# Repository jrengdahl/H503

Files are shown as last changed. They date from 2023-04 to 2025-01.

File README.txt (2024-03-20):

STM32H503RB test board and firmware

This project includes a small OSHPark board for the new H503
microcontroller from ST MIcro, and firmware to run on the board. The
firmware includes OpenMP support for this bare metal microcontroller.

THE CHIP

The STM32H503 is a low-end microcontroller by ST Microelectronics:
-- Cortex-M33 CPU
-- 250 MHz
-- 128K flash
-- 32K RAM
-- typical peripherals for a small micro, including USB Device.
-- ETM trace port

When this chip first became available in early March of 2023, it was in
stock at Mouser for $4.33, and I was able to obtain a few. As of March
2024 they are available in small quantities from Digikey, directly from
ST Micro, and some other suppliers. Try findchips.com to search for
availability. Often such chips are more easily available on a Nucleo
board (although the Nucleo boards do not have trace connectors).

The spec clock for the H503 is 250 Hz. It seems to run reliably up to
350 MHz, and sometimes 400 MHz, at room temperature, and not using all
the chip's features. YMMV.

THE FIRMWARE

The firmware build is managed by an STM32CubeIDE project. The skeleton
of the project was auto-generated from the H503.ioc file. My firmware is
a simple command line interpeter with the following commands:

-- dump memory
-- modify memory
-- fill memory
-- RAM test
-- input from a pin
-- output to a pin
-- calibrate the CPU clock (to make sure the crystal, PLL, and spin-delay loop are correct)
-- set the CPU clock to a given frequency
-- execute a single LDR to a given memory location
-- execute a single STR to a given memory location
-- print a summary of the flash and RAM
-- run a benchmark of the thread switcher
-- display the on-chip temperature sensor reading
-- dump the thread stacks
-- display the state of the free memory system
-- run various OpenMP tests
-- set the debug verbosity level
-- print the help

The command line processor is simple and easily expanded with new commands.

The firmware takes about 40K of flash and 24K of RAM.

For similar L412 and H743 projects, rather than using an FTDI
USB-to-serial cable, or an on-board USB-to-serial chip, I decided to
learn how to use the native on-chip USB for the serial console. I got a
lot of help from Jean Roch's tutorial on using the STM32 USB CDC
library:
https://nefastor.com/microcontrollers/stm32/usb/stm32cube-usb-device-library

When I went to port this firmware over to the H503 I found that, since
the chip is very new, the USB_Device library is not yet available. With
some help from ST tech support, I was able to borrow code from similar
chips (the H743 and L552), and adapt it to the H503.

THREADS

I usually write bare metal firmware, with no OS or RTOS, but I use a
simple non-preemptive threading system, which enables me to architect a
system as a set of cooperating processes. As the concept developed over
many years it has gone by the name of "wait-wake", "plastic fork", and
"not-an-OS", but currently goes by the name of "Bear Metal Threads". Its
characteristics include:

-- very small: the code that gets used at runtime consists of 23 ASM
   instructions. There is a little more for creating threads at powerup. 
-- very fast: a thread switch takes 125 nanoseconds on a 250 MHz M33.
-- non-preemptive: there is no scheduler.
-- threads can run at interrupt level, which can provide prioritization.

OPENMP

One reason I created this project is as a platform to experiment with
bare metal OpenMP. 

OpenMP is a parallel processing extension for C/C++ and Fortran that is
built into GCC. It can be used on modern multi-core PCs running Windows
and Linux. It is most commonly associated with massively parallel
supercomputers such as Frontier and Fugaku (https://www.top500.org). I
aim to show that it can also be useful for multi-threaded and parallel
programming on single and multi-core embedded processors.

The following OpenMP features are working:
-- parallel
-- parallel for
-- single
-- task
-- firstprivate

I have started migrating the powerup code and command line interpreter
to using OpenMP primitives rather than the older threading calls to
spawn new threads.

This is experimental and ongoing.

THE GCC TOOLCHAIN

There are two reasons this firmware requires a special toolchain:

-- The threading system reserves r9 for the preempted thread stack. The
entire firmware must be compiled with the GCC flag "-ffixed-r9", so that
user code does not clobber r9. According to the AAPCS specification, r9
should be untouched by libraries. I have never seen a precompiled ibrary
that observes this rule. Fortunately, the ST-supplied code is always
compiled along with your firmware. Unfortunately, the precompiled newlib
that comes with the standard ARM bare metal GCC toolchain does not
follow the rule and clobbers r9.

-- GCC includes OpenMP, however it is only enabled for platforms that
have a large OS, such as Linux or Windows. The bare metal versions of
the toolchain do not have OpenMP enabled. My build of the GCC bare metal
toolchain has OpenMP enabled.

The Cortex-M33 GCC 12.2 toolchain to be used with this project is found at:
https://github.com/jrengdahl/cross/releases

THE BOARD

The KiCAD project for the board is included, or you can order three
boards from OSHPark for $16.
https://oshpark.com/shared_projects/t9n5Q26a

The board uses the Arduino Nano form factor, but is only partially
pin-compatible. It will fit into a Nano socket, such as this:
https://www.amazon.com/gp/product/B095XVVGQ8. Since the H503 is only
available in a 64-pin LQFP at the moment, in order to fit it on the
board I had to turn it 45 degrees, and delete the middle three pins from
each row of the connector. On the other hand, all pins on the
microcontroller either have a job, are brought out to pins, or are
brought out to solderable test points.

Interesting things about the board are:
-- Arduino Nano form factor
-- can be powered from the USB port
-- uses the on-chip USB for a virtual serial console
-- trace port
-- SPI flash

Otherwise the board is very minimal: power regulator, crystal
oscillator, connectors, a reset button, the BOOT0 button is also an GPIO
input, and one LED. I put a Winbond SPI flash on it because I want to
learn how to use them.

The microcontroller pinout is captured in a CubeMX project,
H503.kicad/H503.ioc. This is a sample CubeMX project I used as reference
for the board design, which shows a possible maximum usage of the pins.
The separate ./H503.ioc used by the firmware project only enables the
pins that are currently supported by the firmware.

Building the board is not hard. I do my soldering under a 1959
StereoZoom microscope using a very fine-tip pencil, and SMT solder paste
applied with a toothpick, or wire solder for through-hole parts. One
thing to watch out for is the USB connector. If you use too little
solder you risk ripping the connector off the board if you are not real
careful with the USB cable. If you use too much solder it can puddle
under the connector and short out the signal pins.

There is a newer version of the board that was manufactured by JLCPCB.
All the small commodity parts are located on the bottom side and are
soldered by JLCPCB. The CPU, connectors, and a couple parts that are
not sourced by JLCPCB are on the top side and have to be hand soldered.

The directory H503-0.1.oshpark contains the KiCad files that were used
for the OSHPark board. The directory H503-0.2.jlcpcb contains the KiCad
files for the JLCPCB board. The "production" subdirectory contains the
zip file that was uploaded to JLCPCB, including the BOM and
pick-and-place files. The directory H503-0.3 contains a slight
modification to the H503-0.2 board layout; mainly, the oscillator
footprint uses larger pads to make it easier to solder by hand. (I have
not had the 0.3 board built yet).

TRACE

One of my retirement presents to myself was a Segger J-Trace probe, so
I put a 20-pin trace port on this board rather than the usual four-pin
Serial Wire Debug port. If you don't have a trace probe you can populate
a 10-pin connector instead, and use a J-link or ST-Link probe. (You
can't fit a 10-pin connector onto a 20 pin header because the end of the
connector won't fit between the 5th and 6th pairs of pins).

One reason I prefer the M7 processors is that they include an on-chip
trace buffer, and a trace probe is not required. I use the free Segger
Ozone debugger, which can display trace for either on-chip or off-chip
trace. Unfortunately, since COVID, M7 chips are nearly impossible for a
hobbyist to obtain. That is why I have been focusing on the L412, and
more recently the H503. (Try lcsc.com if you need M7 chips, I found some
affordable H7B0).

In order to use ETM trace with Cortex-M4 and Cortex-M33 chips, the
following is required:

-- a chip that has trace port or on-chip trace buffer. As far as I know,
all STM32 in 100 pin packages or larger have trace ports. Trace ports on
smaller pinouts are less common. There is no easy way to find which chips
have trace capability, other than reading many data sheets. So far I
have found the STM32H503 and STM32L412 in LQFP-64, and the L412 in
LQFP-32, have 5-pin trace ports. In fact, the L412 seems to be the only
STM32 in LQFP-32 that has a trace port.

Some Cortex-M7 chips from ST Micro have 2K or 4K on-chip trace buffers.
These can be used with Ozone and an inexpensive J-Link Edu, though the
trace depth is limited.

-- a trace probe (unless you have an on-chip trace buffer). Trace probes
are expensive. I am familiar with Lauterbach, which costs in the
vicinity of $10,000. My Segger J-Trace was around $1800. In the UK or EU
check out pdqlogic.com, but they won't ship to the USA. Some people have
used inexpensive USB logic analyzers with the Sigrok software to capture
trace, but such a solution is harder to use
(https://essentialscrap.com/tips/arm_trace).

-- a trace capable debugger. I use Segger Ozone, which is included 
with J-Trace, or it is free for non-commercial use.

-- you have to allocate from two to five pins for the trace port. I have
always used the full five pins.

-- Your board has to have a trace port connector. The traces from the
chip to the connector should be laid out with high speed signalling in
mind. In theory, it might be possible to wire a trace probe to I/O pins
of a Nucleo board, but I would not expect this to work well at fast
clock rates. Though the H503 can run up to 250 MHz (400 MHz overclocked),
on my board the trace becomes flakey above 100 MHz.

-- You need to configure the trace pins. There are two ways to do this:

     -- your software can setup the pins and the ETM at powerup.
        Currently my L412 software does it this way. I based my ETM
        setup code on this project:
        https://github.com/PetteriAimonen/STM32_Trace_Example

     -- You can obtain or write an Ozone script to setup the trace
        pins. Once the pins are setup, Ozone can deal with the ETM and
        TPIU on its own. Segger provides compiled (.pex) scripts for
        certain chips. If your chip is not supported, or you have used a
        different pinout than Segger used, you either have to get them
        to create a .pex for you, or you can write your own script. This
        project includes a redistributable .jdebug script which sets up
        the pins for the H503.

   Having tried both methods, using the script works a lot better. Note
   that the H503 uses a different ETM than the L412. The L412 code will
   not work for the H503. It would be fairly difficult to research and
   write the ETM-M33 setup code, since you not only have to deal with
   the pins, but also the ETM and TPIU, for which I could find no
   easy-to-use documentation or example code. Also, when using the
   script, the trace starts at powerup, whereas if your software sets up
   the ETM, the trace only works after your code runs, and you have to
   stop and restart your program after the setup code before Ozone
   starts receiving trace data.

RTOS-AWARE TRACE

Segger's Ozone debugger can detect RTOS thread switches in order to make
the trace easier to read and understand. If you are using a supported
RTOS they have RTOS-awareness modules you can download and use. If your
RTOS is not supported, or home-brewed like mine, you can tell Ozone
about the thread switching code in the Ozone startup script. The .jdebug
script included with this project does that. There are two prequisites:
your thread switch code must exist in a subroutine call that Ozone can
find, and you have to use Dwarf-4 debug info. Newer editions of GCC,
such as 12.2, emit Dwarf-5 debug data by default, so you have to pass
-gdwarf-4 to the GCC and G++ compilers.

The newer version of Ozone supports Dwarf-5, but I have not tried
Dwarf-5 yet.

JLINK

There is an alternate H503-edu.jdebug file that works with a non-trace
Jlink. The J-link Edu comes with a 10-pin high density conector that
will work with this board if you install a 10 pin connector (or cut half
the pins from the 20-pin connector). Jlink EDU is $60 at
https://shop-us.segger.com/product/j-link-edu-mini-8-08-91 or
at Mouser or Digikey.

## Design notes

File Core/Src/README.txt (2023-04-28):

Bear Metal Shell
A small embedded command line processor.

Bear Metal Threads
Extremely minimal non-preemptive thread switching for bare metal.

The original version of this code was developed in 2009 for a home
project that was intended to result in a digital controller for my
trolling motor that had a burned out speed control switch. The
controller was a Luminary Micro Cortex-M3 eval board. The motor driver
was made for RC model planes. It worked fine on dry land, but when I got
it into the water it went poof after about a minute and the magic smoke
came out. Evidently the motor's resistance and current were compatible
with the RC drive circuit, but the inductance of the trolling motor was
a lot more than an airplane motor. Under load, the inductive kick took
out the catch diodes.

The motor controller wound up in the scrap pile, I got a new mechnical
switch for the boat motor and gave it away, but the firmware lives on,
and on, and on. It found many uses, including some products of my
employer. The files here are derived from the original code I wrote for
the Luminary Micro Cortex-M3, or are newly written since I retired.

Manifest

My contributions in this directory include, but are not necessarily
limited to the following files. The list includes the #include files
which should be located in a nearby direcetory such as ../Inc. Most
other files in these directories are from ST Micro, and are probably 
auto-generated by STM CubeMX.

README.txt          This file
RamTest.cpp         A minimal RAM tester
background.cpp      Powerup init for my code, then it becomes the background polling loop
bear.cpp            Print the Bear Metal logo.
bogodelay.cpp       Delay the specificed number of CPU cycles
dump.cpp            Memory dump
getline.cpp         Get a line of input, with command line editing and history
interp.cpp          The command line interprter
libgomp.cpp         OpenMP library for bare metal (experimental, under development)
printf.cpp          printf
serial.cpp          Console interface routines for serial, USB VCP, or whatever 
summary.cpp         Print a summary of the memory
thread.cpp          The implementation of Bear Metal Threads

CriticalRegion.hpp  Disable interrupts around a block of code. Safe for break, return, etc.
FIFO.hpp            A wait-free, single-writer-single-reader FIFO (aka ring buffer)
ThreadFIFO.hpp      A subclass if FIFO which implements thread suspend/resume.
atomic.h            Wrap a small block of code with LDREX/STREX, making its operation on a variable atomic.
bogodelay.hpp       For bogodelay.cpp
boundaries.h        Mapping of linker regions for summary.cpp
cmsis.h             A wrapper for cmsis_compiler.h which remedies some ommissions.
cyccnt.hpp          Support for the cycle counter, including high precision timing measurements.
libgomp.hpp         For libcomp.cpp
local.h             Local config and definitions for interp, getline, printf, etc.
random.hpp          A famous random number generator, simple, fast, and fairly good.
serial.h            For serial.cpp.
thread.hpp          For Thread.cpp.

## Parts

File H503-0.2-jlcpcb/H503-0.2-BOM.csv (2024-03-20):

Id | Designator | Footprint | Quantity | Designation | Supplier and ref
1 | X1 | Oscillator_SMD_ECS_2520MV-xxx-xx-4Pin_2.5x2.0mm | 1 | ECS-2520MV-080-CN
2 | TP1,TP3,TP7,TP14,TP9,TP6,TP11,TP5,TP8,TP12,TP4,TP13,TP2,TP10 | TestPoint_THTPad_D1.0mm_Drill0.5mm_min | 14 | TestPoint
3 | BOOT1,RESET1 | SW_SPST_B3U-1000P | 2 | SW_Push
4 | J3 | PinHeader_2x10_P1.27mm_Vertical | 1 | Conn_02x10_Odd_Even
5 | U4 | SOT-23-6 | 1 | WE-TVS-82400102
6 | J4 | USB_Micro-B_Amphenol_10118194_Horizontal | 1 | USB_B_Micro
7 | U2 | LQFP-64_10x10mm_P0.5mm | 1 | STM32H503RBTx
8 | U3 | SOIC-8_5.23x5.23mm_P1.27mm | 1 | W25Q128JVS
9 | D1 | LED_PLCC-2_3.4x3.0mm_KA | 1 | LED
10 | C10,C14,C1,C9,C8,C7,C2,C13 | C_0603_1608Metric | 8 | .1uf
11 | U1 | SOT-23-3 | 1 | XC6206P332MR
12 | R1,R2,R3 | R_0603_1608Metric | 3 | 10K
13 | J1,J2,J6,J5 | PinHeader_1x06_P2.54mm_Vertical__min | 4 | Conn_01x06_Pin
14 | FB1 | C_0603_1608Metric | 1 | ~
15 | D2,D3 | D_SOD-323 | 2 | 1N5819WS
16 | C11,C12 | C_0805_2012Metric | 2 | 2.2uf
17 | R9 | R_0603_1608Metric | 1 | 150
18 | C3,C4 | C_0805_2012Metric | 2 | 1uf

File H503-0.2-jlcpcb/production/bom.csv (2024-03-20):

Designator | Footprint | Quantity | Value | LCSC Part #
BOOT1, RESET1 | SW_SPST_B3U-1000P | 2 | SW_Push
C1, C10, C13, C14, C2, C7, C8, C9 | 0603 | 8 | .1uf | C14663
C11, C12 | 0805 | 2 | 2.2uf | C49217
C3, C4 | 0805 | 2 | 1uf | C28323
D1 | LED_PLCC-2_3.4x3.0mm_KA | 1 | LED
D2, D3 | D_SOD-323 | 2 | 1N5819WS | C191023
FB1 | 0603 | 1 | ~ | C1002
J1, J2, J5, J6 | PinHeader_1x06_P2.54mm_Vertical__min | 4 | Conn_01x06_Pin
J3 | PinHeader_2x10_P1.27mm_Vertical | 1 | Conn_02x10_Odd_Even
J4 | USB_Micro-B_Amphenol_10118194_Horizontal | 1 | USB_B_Micro
R1, R2, R3 | 0603 | 3 | 10K | C25804
R9 | 0603 | 1 | 150 | C22808
TP1, TP10, TP11, TP12, TP13, TP14, TP2, TP3, TP4, TP5, TP6, TP7, TP8, TP9 | TestPoint_THTPad_D1.0mm_Drill0.5mm_min | 14 | TestPoint
U1 | SOT-23-3 | 1 | XC6206P332MR | C5446
U2 | LQFP-64_10x10mm_P0.5mm | 1 | STM32H503RBTx
U3 | SOIC-8_5.23x5.23mm_P1.27mm | 1 | W25Q128JVS
U4 | SOT-23-6 | 1 | WE-TVS-82400102
X1 | Oscillator_SMD_ECS_2520MV-xxx-xx-4Pin_2.5x2.0mm | 1 | ECS-2520MV-080-CN

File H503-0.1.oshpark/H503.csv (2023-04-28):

Source: | C:\STM32\H503\H503.kicad\H503.kicad_sch
Date: | 4/27/2023 8:32:40 PM
Tool: | Eeschema (7.0.0)
Generator: | C:\Program Files\KiCad\7.0\bin\scripting\plugins/bom_csv_grouped_by_value.py
Component Count: | 46
Collated Components:
Item | Qty | Reference(s) | Value | LibPart | Footprint | Datasheet | DNP
1 | 2 | BOOT1, RESET1 | SW_Push | Switch:SW_Push | Button_Switch_SMD:SW_SPST_B3U-1000P | https://www.digikey.com/en/products/detail/omron-electronics-inc-emc-div/B3U-1000P/1534338
2 | 8 | C1, C2, C7, C8, C9, C10, C13, C14 | .1uf | Device:C | Capacitor_SMD:C_0603_1608Metric | ~
3 | 1 | C3 | 1uf | Device:C | Capacitor_SMD:C_0805_2012Metric | ~
4 | 1 | C6 | 2.2uf | Device:C_Polarized | Capacitor_SMD:C_0805_2012Metric | ~
5 | 2 | C11, C12 | 2.2uf | Device:C | Capacitor_SMD:C_0805_2012Metric | ~
6 | 1 | D1 | LED | Device:LED | LED_SMD:LED_PLCC-2_3.4x3.0mm_KA | https://www.digikey.com/en/products/detail/broadcom-limited/ASMM-CA03-AR402/13906996
7 | 1 | FB1 | ~ | Device:FerriteBead_Small | Capacitor_SMD:C_0805_2012Metric_Pad1.18x1.45mm_HandSolder | https://www.digikey.com/en/products/detail/bourns-inc/MH2029-601Y/1970502
8 | 4 | J1, J2, J5, J6 | Conn_01x06_Pin | Connector:Conn_01x06_Pin | BearMetal:PinHeader_1x06_P2.54mm_Vertical__min | ~
9 | 1 | J3 | Conn_02x10_Odd_Even | Connector_Generic:Conn_02x10_Odd_Even | Connector_PinHeader_1.27mm:PinHeader_2x10_P1.27mm_Vertical | https://www.digikey.com/en/products/detail/sullins-connector-solutions/GRPB102VWVN-RC/1786460
10 | 1 | J4 | USB_B_Micro | Connector:USB_B_Micro | Connector_USB:USB_Micro-B_Amphenol_10118194_Horizontal | https://www.digikey.com/en/products/detail/amphenol-cs-fci/10118194-0001LF/2785389
11 | 4 | R1, R2, R3, R4 | 10K | Device:R_US | Resistor_SMD:R_0805_2012Metric | ~
12 | 1 | R9 | 150 | Device:R_US | Resistor_SMD:R_0805_2012Metric | ~
13 | 14 | TP1, TP2, TP3, TP4, TP5, TP6, TP7, TP8, TP9, TP10, TP11, TP12, TP13, TP14 | TestPoint | Connector:TestPoint | BearMetal:TestPoint_THTPad_D1.0mm_Drill0.5mm_min | ~
14 | 1 | U1 | AP2205-3.3Y | Regulator_Linear:AP2204R-3.3 | Package_TO_SOT_SMD:SOT-89-3 | https://www.diodes.com/assets/Datasheets/AP2204.pdf
15 | 1 | U2 | STM32H503RBTx | BearMetal:STM32H503RBTx | Package_QFP:LQFP-64_10x10mm_P0.5mm | https://www.st.com/resource/en/datasheet/stm32h7b0rb.pdf
16 | 1 | U3 | W25Q128JVS | Memory_Flash:W25Q128JVS | Package_SO:SOIC-8_5.23x5.23mm_P1.27mm | http://www.winbond.com/resource-files/w25q128jv_dtr%20revc%2003272018%20plus.pdf
17 | 1 | U4 | WE-TVS-82400102 | Power_Protection:WE-TVS-82400102 | Package_TO_SOT_SMD:SOT-23-6 | https://katalog.we-online.de/pbs/datasheet/82400102.pdf
18 | 1 | X1 | ECS-2520MV-080-CN | Oscillator:ECS-2520MV-xxx-xx | Oscillator:Oscillator_SMD_ECS_2520MV-xxx-xx-4Pin_2.5x2.0mm | https://www.digikey.com/en/products/detail/ecs-inc/ECS-2520MV-080-CN-TR/9742386

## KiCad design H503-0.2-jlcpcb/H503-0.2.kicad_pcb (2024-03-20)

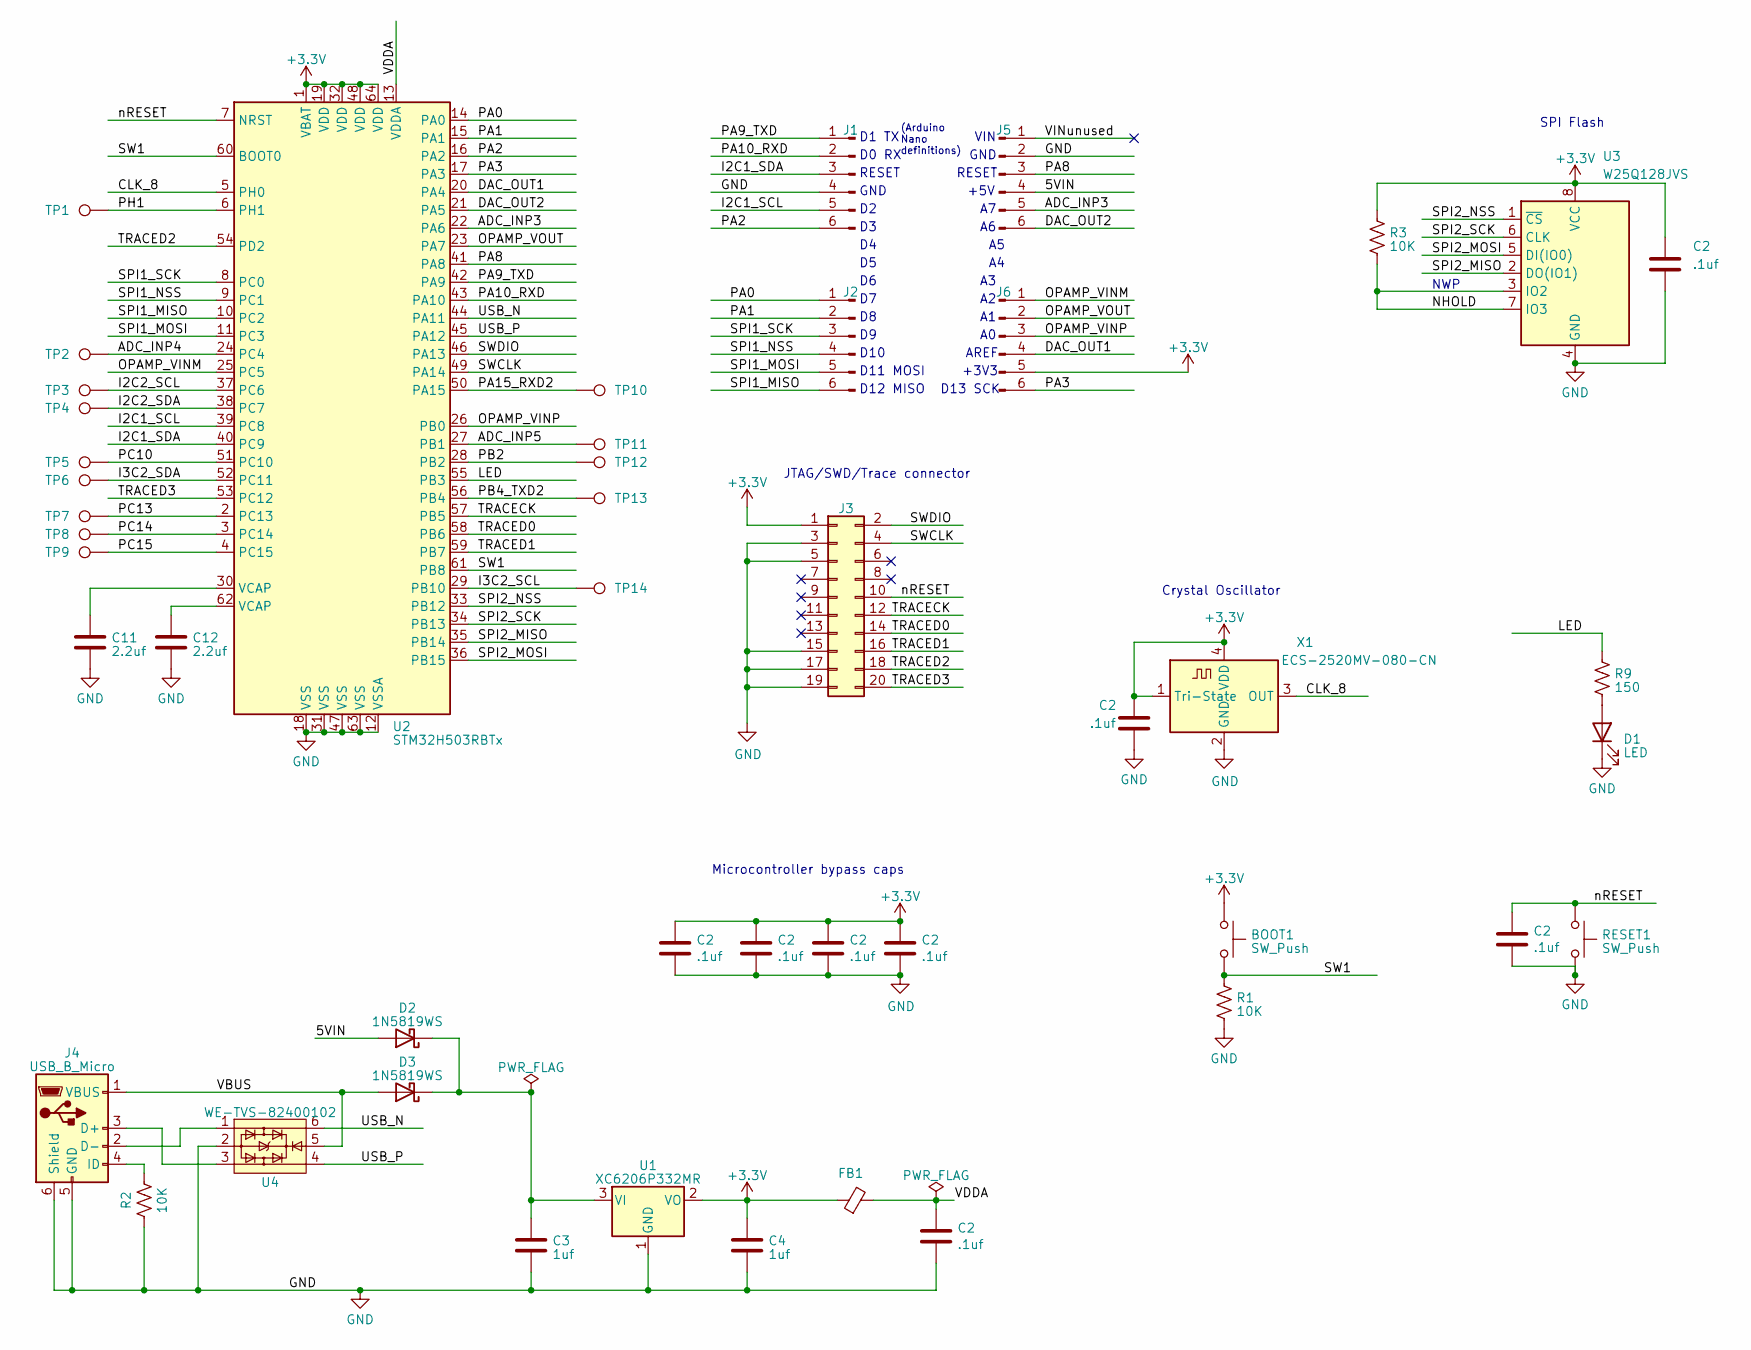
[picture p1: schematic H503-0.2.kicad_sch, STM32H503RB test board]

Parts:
BOOT1: SW_Push; SW_SPST_B3U-1000P
C2: .1uf; C_0603_1608Metric; LCSC C14663
C3, C4: 1uf; C_0805_2012Metric; LCSC C28323
C11, C12: 2.2uf; C_0805_2012Metric; LCSC C49217
D1: LED; LED_PLCC-2_3.4x3.0mm_KA
D2, D3: 1N5819WS; D_SOD-323; LCSC C191023
FB1: C_0603_1608Metric; LCSC C1002
J1, J2, J5, J6: Conn_01x06_Pin; PinHeader_1x06_P2.54mm_Vertical__min
J3: Conn_02x10_Odd_Even; PinHeader_2x10_P1.27mm_Vertical
J4: USB_B_Micro; USB_Micro-B_Amphenol_10118194_Horizontal
R1, R2, R3: 10K; R_0603_1608Metric; LCSC C25804
R9: 150; R_0603_1608Metric; LCSC C22808
RESET1: SW_Push; SW_SPST_B3U-1000P
TP1, TP2, TP3, TP4, TP5, TP6, TP7, TP8, TP9, TP10, TP11, TP12, TP13, TP14: TestPoint; TestPoint_THTPad_D1.0mm_Drill0.5mm_min
U1: XC6206P332MR; SOT-23-3; LCSC C5446
U2: STM32H503RBTx; LQFP-64_10x10mm_P0.5mm
U3: W25Q128JVS; SOIC-8_5.23x5.23mm_P1.27mm
U4: WE-TVS-82400102; SOT-23-6
X1: ECS-2520MV-080-CN; Oscillator_SMD_ECS_2520MV-xxx-xx-4Pin_2.5x2.0mm

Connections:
/5VIN: D2.2 (A), J5.4
/ADC_INP3: J5.5, U2.22 (PA6)
/ADC_INP4: TP2.1, U2.24 (PC4)
/ADC_INP5: TP11.1, U2.27 (PB1)
/CLK_8: U2.5 (PH0), X1.3 (OUT)
/DAC_OUT1: J6.4, U2.20 (PA4)
/DAC_OUT2: J5.6, U2.21 (PA5)
/I2C1_SCL: J1.5, U2.39 (PC8)
/I2C1_SDA: J1.3, U2.40 (PC9)
/I2C2_SCL: TP3.1, U2.37 (PC6)
/I2C2_SDA: TP4.1, U2.38 (PC7)
/I3C2_SCL: TP14.1, U2.29 (PB10)
/I3C2_SDA: TP6.1, U2.52 (PC11)
/LED: R9.2, U2.55 (PB3)
/NHOLD: R3.2, U3.3 (IO2), U3.7 (IO3)
/OPAMP_VINM: J6.1, U2.25 (PC5)
/OPAMP_VINP: J6.3, U2.26 (PB0)
/OPAMP_VOUT: J6.2, U2.23 (PA7)
/PA0: J2.1, U2.14 (PA0)
/PA1: J2.2, U2.15 (PA1)
/PA2: J1.6, U2.16 (PA2)
/PA3: J6.6, U2.17 (PA3)
/PA8: J5.3, U2.41 (PA8)
/PA9_TXD: J1.1, U2.42 (PA9)
/PA10_RXD: J1.2, U2.43 (PA10)
/PA15_RXD2: TP10.1, U2.50 (PA15)
/PB2: TP12.1, U2.28 (PB2)
/PB4_TXD2: TP13.1, U2.56 (PB4)
/PC10: TP5.1, U2.51 (PC10)
/PC13: TP7.1, U2.2 (PC13)
/PC14: TP8.1, U2.3 (PC14)
/PC15: TP9.1, U2.4 (PC15)
/PH1: TP1.1, U2.6 (PH1)
/SPI1_MISO: J2.6, U2.10 (PC2)
/SPI1_MOSI: J2.5, U2.11 (PC3)
/SPI1_NSS: J2.4, U2.9 (PC1)
/SPI1_SCK: J2.3, U2.8 (PC0)
/SPI2_MISO: U2.35 (PB14), U3.2 (DO(IO1))
/SPI2_MOSI: U2.36 (PB15), U3.5 (DI(IO0))
/SPI2_NSS: U2.33 (PB12), U3.1 (~CS)
/SPI2_SCK: U2.34 (PB13), U3.6 (CLK)
/SW1: BOOT1.2, R1.1, U2.60 (BOOT0), U2.61 (PB8)
/SWCLK: J3.4, U2.49 (PA14)
/SWDIO: J3.2, U2.46 (PA13)
/TRACECK: J3.12, U2.57 (PB5)
/TRACED0: J3.14, U2.58 (PB6)
/TRACED1: J3.16, U2.59 (PB7)
/TRACED2: J3.18, U2.54 (PD2)
/TRACED3: J3.20, U2.53 (PC12)
/USB_N: U2.44 (PA11), U4.6
/USB_P: U2.45 (PA12), U4.4
/VBUS: D3.2 (A), J4.1 (VBUS), U4.5
/VINunused: J5.1
GND: C2.2, C3.2, C4.2, C11.2, C12.2, D1.1 (K), J1.4, J3.3, J3.5, J3.15, J3.17, J3.19, J4.5 (GND), J4.6 (Shield), J5.2, R1.2, R2.1, RESET1.2, U1.1 (GND), U2.12 (VSSA), U2.18 (VSS), U2.31 (VSS), U2.47 (VSS), U2.63 (VSS), U3.4 (GND), U4.2, X1.2 (GND); also elsewhere on the board
unnamed: C11.1, U2.30 (VCAP)
unnamed: C12.1, U2.62 (VCAP)
unnamed: D1.2 (A), R9.1
unnamed: C3.1, D2.1 (K), D3.1 (K), U1.3 (VI)
unnamed: J4.3 (D+), U4.3
unnamed: J4.2 (D-), U4.1
unnamed: J4.4 (ID), R2.2

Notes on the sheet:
+3V3
SPI Flash
VIN
NWP
+5V
GND
Microcontroller bypass caps
D13 SCK
D12 MISO
Crystal Oscillator
D1 TX
RESET
JTAG/SWD/Trace connector
D11 MOSI
D0 RX
(Arduino Nano definitions)
AREF
D10

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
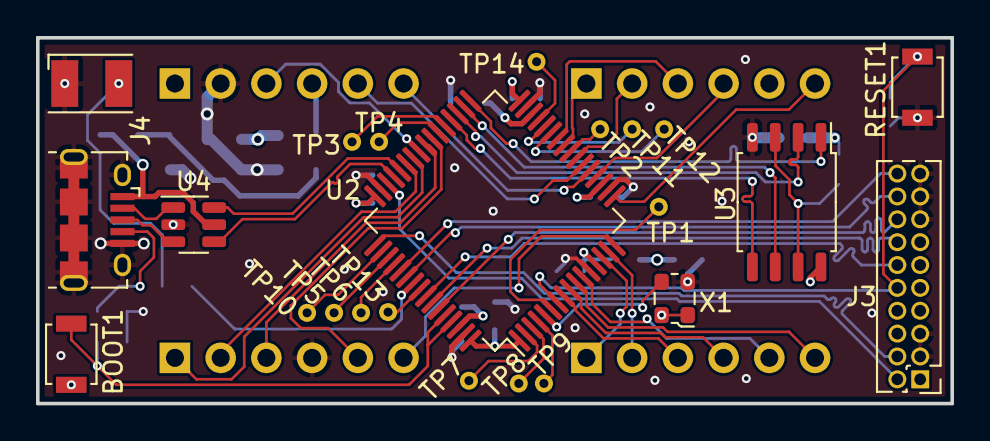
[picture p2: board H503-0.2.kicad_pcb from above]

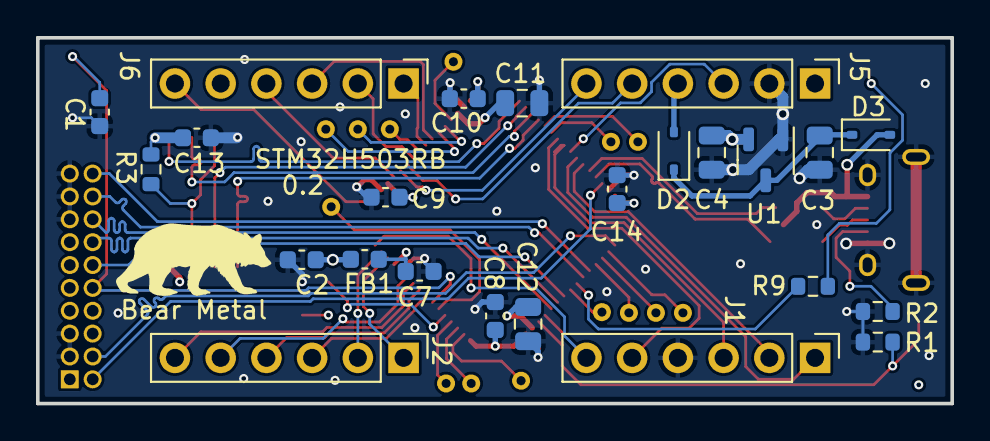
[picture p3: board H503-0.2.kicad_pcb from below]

Board: 4 copper layers, 50.8 x 20.3 mm, 47 parts (24 on the bottom side), 63 nets.

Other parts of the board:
C1, C7, C8, C9, C10, C13, C14: .1uf; C_0603_1608Metric

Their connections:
GND: C1.2, C7.2, C8.2, C9.2, C10.2, C13.2, C14.2; also elsewhere on the board

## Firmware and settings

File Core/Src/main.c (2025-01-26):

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
/* Includes ------------------------------------------------------------------*/
#include "main.h"
#include "adc.h"
#include "icache.h"
#include "memorymap.h"
#include "spi.h"
#include "tim.h"
#include "usb.h"
#include "gpio.h"

/* USER CODE BEGIN Includes */
#include "usb_device.h"
#include "usbd_cdc_if.h"
/* USER CODE END Includes */


/* USER CODE BEGIN PV */

unsigned CPU_CLOCK_FREQUENCY = 100;

/* USER CODE END PV */

void SystemClock_Config(void);
/**
  * @brief  The application entry point.
  * @retval int
  */
int main(void)
{

  /* MCU Configuration--------------------------------------------------------*/

  /* Reset of all peripherals, Initializes the Flash interface and the Systick. */
  HAL_Init();

  /* Configure the system clock */
  SystemClock_Config();

  /* Initialize all configured peripherals */
  MX_GPIO_Init();
  MX_USB_PCD_Init();
  MX_ICACHE_Init();
  MX_ADC1_Init();
  MX_TIM2_Init();
  MX_SPI2_Init();
  MX_SPI1_Init();
  /* USER CODE BEGIN 2 */

  MX_USB_Device_Init();
  vcp_init();

  /* Perform ADC calibration */
  if (HAL_ADCEx_Calibration_Start(&hadc1, ADC_SINGLE_ENDED) != HAL_OK)
    {
    /* Calibration Error */
    Error_Handler();
    }

  /* start TIM2, whihc is used for the 1 usec clock */
  HAL_TIM_Base_Start(&htim2);

  extern void background();
  background();

  /* USER CODE END 2 */

  /* Infinite loop */
  /* USER CODE BEGIN WHILE */
  while (1)
  {
    /* USER CODE END WHILE */

    /* USER CODE BEGIN 3 */
  }
  /* USER CODE END 3 */
}

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
/* USER CODE BEGIN 4 */

void SystemClock_PLL_Config(unsigned freq)
{
  unsigned PLLN;
  unsigned PLLP;

  if(freq > 128)
  {
    PLLN = freq;
    PLLP = 2;
  }
  else
  {
    PLLN = freq*2;
    PLLP = 4;
  }

  RCC_OscInitTypeDef RCC_OscInitStruct = {0};
  RCC_ClkInitTypeDef RCC_ClkInitStruct = {0};

  /** Configure the main internal regulator output voltage
  */
  __HAL_PWR_VOLTAGESCALING_CONFIG(PWR_REGULATOR_VOLTAGE_SCALE0);

  while(!__HAL_PWR_GET_FLAG(PWR_FLAG_VOSRDY)) {}

  /** Initializes the RCC Oscillators according to the specified parameters
  * in the RCC_OscInitTypeDef structure.
  */
  RCC_OscInitStruct.OscillatorType = RCC_OSCILLATORTYPE_HSE;
  RCC_OscInitStruct.HSEState = RCC_HSE_BYPASS;
  RCC_OscInitStruct.PLL.PLLState = RCC_PLL_ON;
  RCC_OscInitStruct.PLL.PLLSource = RCC_PLL1_SOURCE_HSE;
  RCC_OscInitStruct.PLL.PLLM = 4;
  RCC_OscInitStruct.PLL.PLLN = PLLN;
  RCC_OscInitStruct.PLL.PLLP = PLLP;
  RCC_OscInitStruct.PLL.PLLQ = 3;
  RCC_OscInitStruct.PLL.PLLR = 2;
  RCC_OscInitStruct.PLL.PLLRGE = RCC_PLL1_VCIRANGE_1;
  RCC_OscInitStruct.PLL.PLLVCOSEL = RCC_PLL1_VCORANGE_WIDE;
  RCC_OscInitStruct.PLL.PLLFRACN = 0;
  if (HAL_RCC_OscConfig(&RCC_OscInitStruct) != HAL_OK)
  {
    Error_Handler();
  }

  /** Initializes the CPU, AHB and APB buses clocks
  */
  RCC_ClkInitStruct.ClockType = RCC_CLOCKTYPE_HCLK|RCC_CLOCKTYPE_SYSCLK
                              |RCC_CLOCKTYPE_PCLK1|RCC_CLOCKTYPE_PCLK2
                              |RCC_CLOCKTYPE_PCLK3;
  RCC_ClkInitStruct.SYSCLKSource = RCC_SYSCLKSOURCE_PLLCLK;
  RCC_ClkInitStruct.AHBCLKDivider = RCC_SYSCLK_DIV1;
  RCC_ClkInitStruct.APB1CLKDivider = RCC_HCLK_DIV1;
  RCC_ClkInitStruct.APB2CLKDivider = RCC_HCLK_DIV1;
  RCC_ClkInitStruct.APB3CLKDivider = RCC_HCLK_DIV1;

  if (HAL_RCC_ClockConfig(&RCC_ClkInitStruct, freq/50) != HAL_OK)
  {
    Error_Handler();
  }

  CPU_CLOCK_FREQUENCY = freq;
}

void SystemClock_HSI_Config(void)
{
  RCC_OscInitTypeDef RCC_OscInitStruct = {0};
  RCC_ClkInitTypeDef RCC_ClkInitStruct = {0};

  /** Configure the main internal regulator output voltage
  */
  __HAL_PWR_VOLTAGESCALING_CONFIG(PWR_REGULATOR_VOLTAGE_SCALE0);

  while(!__HAL_PWR_GET_FLAG(PWR_FLAG_VOSRDY)) {}

  /** Initializes the RCC Oscillators according to the specified parameters
  * in the RCC_OscInitTypeDef structure.
  */
  RCC_OscInitStruct.OscillatorType = RCC_OSCILLATORTYPE_HSI;
  RCC_OscInitStruct.HSIState = RCC_HSI_ON;
  RCC_OscInitStruct.HSIDiv = RCC_HSI_DIV2;
  RCC_OscInitStruct.HSICalibrationValue = RCC_HSICALIBRATION_DEFAULT;
  RCC_OscInitStruct.PLL.PLLState = RCC_PLL_NONE;
  if (HAL_RCC_OscConfig(&RCC_OscInitStruct) != HAL_OK)
  {
    Error_Handler();
  }

  /** Initializes the CPU, AHB and APB buses clocks
  */
  RCC_ClkInitStruct.ClockType = RCC_CLOCKTYPE_HCLK|RCC_CLOCKTYPE_SYSCLK
                              |RCC_CLOCKTYPE_PCLK1|RCC_CLOCKTYPE_PCLK2
                              |RCC_CLOCKTYPE_PCLK3;
  RCC_ClkInitStruct.SYSCLKSource = RCC_SYSCLKSOURCE_HSI;
  RCC_ClkInitStruct.AHBCLKDivider = RCC_SYSCLK_DIV1;
  RCC_ClkInitStruct.APB1CLKDivider = RCC_HCLK_DIV1;
  RCC_ClkInitStruct.APB2CLKDivider = RCC_HCLK_DIV1;
  RCC_ClkInitStruct.APB3CLKDivider = RCC_HCLK_DIV1;

  if (HAL_RCC_ClockConfig(&RCC_ClkInitStruct, FLASH_LATENCY_0) != HAL_OK)
  {
    Error_Handler();
  }
}


/* USER CODE END 4 */
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


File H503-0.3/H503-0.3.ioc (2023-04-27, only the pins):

Mcu.UserName=STM32H503RBTx
PA0.Signal=SPI3_NSS
PA1.Signal=SPI3_SCK
PA10.Signal=USART1_RX
PA11.Signal=USB_DM
PA12.Signal=USB_DP
PA13(JTMS/SWDIO).GPIO_Label=SWDIO
PA13(JTMS/SWDIO).Signal=DEBUG_JTMS-SWDIO
PA14(JTCK/SWCLK).GPIO_Label=SWCLK
PA14(JTCK/SWCLK).Signal=DEBUG_JTCK-SWCLK
PA15(JTDI).Signal=USART2_RX
PA2.Signal=SPI3_MISO
PA3.Signal=SPI3_MOSI
PA4.Signal=COMP_DAC11_group
PA5.Signal=COMP_DAC12_group
PA6.Signal=ADCx_INP3
PA7.Signal=SharedAnalog_PA7
PA8.GPIO_Label=PA8
PA8.Signal=GPIO_Input
PA9.Signal=USART1_TX
PB0.Signal=OPAMP1_VINP
PB1.Signal=ADCx_INP5
PB10.Signal=I3C2_SCL
PB12.Signal=SPI2_NSS
PB13.Signal=SPI2_SCK
PB14.Signal=SPI2_MISO
PB15.Signal=SPI2_MOSI
PB2.GPIO_Label=PB2
PB2.Signal=GPIO_Input
PB3(JTDO/TRACESWO).GPIO_Label=LED
PB3(JTDO/TRACESWO).Signal=GPIO_Output
PB4(NJTRST).Signal=USART2_TX
PB5.GPIO_Label=TRACECK
PB5.Signal=DEBUG_TRACECLK
PB6.GPIO_Label=TRACED0
PB6.Signal=DEBUG_TRACED0
PB7.GPIO_Label=TRACED1
PB7.Signal=DEBUG_TRACED1
PB8.GPIO_Label=SW1
PB8.Signal=GPIO_Input
PC0.Signal=SPI1_SCK
PC1.Signal=SPI1_NSS
PC10.GPIO_Label=PC10
PC10.Signal=GPIO_Input
PC11.Signal=I3C2_SDA
PC12.GPIO_Label=TRACED3
PC12.Signal=DEBUG_TRACED3
PC13.GPIO_Label=PC13
PC13.Signal=GPIO_Input
PC14-OSC32_IN(OSC32_IN).GPIO_Label=PC14
PC14-OSC32_IN(OSC32_IN).Signal=GPIO_Input
PC15-OSC32_OUT(OSC32_OUT).GPIO_Label=PC15
PC15-OSC32_OUT(OSC32_OUT).Signal=GPIO_Input
PC2.Signal=SPI1_MISO
PC3.Signal=SPI1_MOSI
PC4.Signal=ADCx_INP4
PC5.Signal=OPAMP1_VINM
PC6.Signal=I2C2_SCL
PC7.Signal=I2C2_SDA
PC8.Signal=I2C1_SCL
PC9.Signal=I2C1_SDA
PD2.GPIO_Label=TRACED2
PD2.Signal=DEBUG_TRACED2
PH0-OSC_IN(PH0).Signal=RCC_OSC_IN
PH1-OSC_OUT(PH1).GPIO_Label=PH1
PH1-OSC_OUT(PH1).Signal=GPIO_Input

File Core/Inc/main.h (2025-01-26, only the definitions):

#define SPI1_NSS_Pin GPIO_PIN_1
#define SPI1_NSS_GPIO_Port GPIOC
#define TRIGGER2_Pin GPIO_PIN_2
#define TRIGGER2_GPIO_Port GPIOA
#define SPI2_NSS_Pin GPIO_PIN_12
#define SPI2_NSS_GPIO_Port GPIOB
#define PA8_Pin GPIO_PIN_8
#define PA8_GPIO_Port GPIOA
#define TRIGGER0_Pin GPIO_PIN_9
#define TRIGGER0_GPIO_Port GPIOA
#define TRIGGER1_Pin GPIO_PIN_10
#define TRIGGER1_GPIO_Port GPIOA
#define SWDIO_Pin GPIO_PIN_13
#define SWDIO_GPIO_Port GPIOA
#define SWCLK_Pin GPIO_PIN_14
#define SWCLK_GPIO_Port GPIOA
#define LED_Pin GPIO_PIN_3
#define LED_GPIO_Port GPIOB
#define SW1_Pin GPIO_PIN_8
#define SW1_GPIO_Port GPIOB

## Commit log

2023-04-27 add KiCad project for the H503 board
    [H503-B_Cu.gbr, H503-B_Mask.gbr, H503-B_Silkscreen.gbr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]
2023-04-28 update schematic and create BOM
    [H503.csv, H503.kicad_sch]
2023-04-29 optimize inline assembly for suspend and resume in thread.cpp
    Achieved nearly 8% improvement.
2023-04-29 One more optimization for thread.cpp.
    Now nearly 10% improvement.
    A thead switch now costs about 125 ns.
2023-04-30 add time/switch to thread benchmark test
    mods to README
2023-05-02 got trace working
    Delete trace pins from my project -- let the debugger manage them.
    Drop speed from 250 to 50 MHz to get trace to work. Will later bump it back up as much as possible and still have trace work.
2023-05-03 change clock to 100 MHz
    trace seems to trip once in a while at 150
2023-05-05 add and use redistributable version of trace pin setup JScript
2023-05-05 fix .gitignore and add Drivers to the git project
    so the project is complete and can be compiled without
    re-generating the auto source code
2023-05-05 change PLL setup to make it easier to change CPU frequency on the fly
    try to fix __NOINLINE in STM32H5xx_hal_def.h
    [H503.ioc, main.c]
2023-05-05 make CPU frequency settable, step 1
    try again to fix __NOINLINE
    [H503.ioc, main.c]
2023-05-05 trying to make CPU clk variable, first try failed
    changed cyccnt.hpp
    added clk command to interp
    [H503.ioc, interp.cpp]
2023-05-05 add warning about trace if clock is over 100 MHz
2023-05-07 snapshot, working on changes to thread switches to make them comprehensible to RTOS-aware tracing
    code works, but trace timeline still doesn't have it exactly right
2023-05-08 got RTOS-awareness working for Bear Metal Threads
    The key is refactoring the switch routines, and
    passing -gdwarf-4 to the compiler.
2023-05-08 optimize thread switching for RTOS awareness
2023-05-24 add tmp (temperature) command
    refactor thread to context
2023-05-24 add omp test
    add verbose command
    change USB serial so only one thread switch is required per newline
    align omp thread stacks for debugging
2023-05-31 rewrote context switching for OMP
    (worked on the second try)
2023-06-02 add "stk" command to dump stacks
    add "id" to omp_thread
    fix omp_get_thread_num
    add operator bool to Port
    adjust stacks and number of OMP threads and tasks to conserve memory on
    make background use the "user stack" rather than the end of memory
    implement mutex.h for H503
    add mutex to printf
    add Port to list of thread switches in H503.jdebug
    [H503.ioc, interp.cpp]
2023-06-23 partial rewrite of libgomp, moving toward using OpenMP as RTOS
    more implementation of teams
    add fast, simple malloc
    add arg to spawn
    It works! On the first try!
    Improved stk command.
    Added arg to omp 0 test (number of threads).
2023-06-27 add "single" test
    single does not work, need to add code so interp is a OMP thread
    rewrite GOMP_barrier
    [interp.cpp]
2023-07-27 got permute to work
    renamed ThreadFIFO to ContextFIFO
    fixed ASM for ContextFIFO
    add name string to omp_thread for debug
    make background and inter OMP threads
    mutex.h uses ContxtFIFO instead of Port
    improved "stk" command
    fixed member chain walking in libgomp
    added _writenl
    [interp.cpp]
2023-07-28 found a better way to run background and interp
    moved background polling loop back to background.cpp, using
    a team of two threads to run background loop (0) and interp (1)
2023-07-29 improve debug reporting of thread IDs
2023-08-04 fix memory leak in malloc
    add "mem" command to display free memory pool state
    [interp.cpp]
2024-01-05 Add libgomp_reinit to reset default number of threads after an OpenMP program has terminated.
    Add op_get_wtime and omp_get_wtick, but they are based on the 32-bit cycle counter which is only good for 42 seconds at 100 MHz, or
    17 seconds at 250 MHz. I need to fire up one of the 64 bit timers.
2024-01-05 Add libgomp_reinit to reset default number of threads after an OpenMP program has terminated.
    (Forgot to stage the changes on the last commit).
    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
    [interp.cpp]
2024-01-05 Migrate project to new version of STM32CubeIDE.
    This updates a lot of drivers and also sometimes causes code generation to change.
    Changed cmsis.h so that the definition of __NOINLINE matches the HAL version, to suppress redefinition warning.
    Also had to change one CubeMX clock tree setting to get rid of a new error message.
    [H503.ioc, main.c]
2024-01-05 Print build date/time stamp at startup.
2024-01-06 Rewrote omp_get_wtime to use TIM2, which is clocked at 1 MHz.
    Enabled and setup TIM2.
    Added test of omp_get_wtime to the calibrate command.
2024-01-06 Update TIM2 prescaler when clock frequency is changed so that TIM2 always counts microseconds.
    Daisy-chain omp.h with a local version to add customized definitions.
    Add single-precision floating point versions of omp_get_wtime and omp_get_wtick.
2024-01-09 Rewrite threading benchmark; remove TestStack; (not working yet).
    context.hpp: added function to return the current Context pointer (r9).
    interp.cpp: add help for omp tests.
    [interp.cpp]
2024-01-10 Optimized OpenMP thread scheduler; rather than a yield in a spin loo, the non-busy threads now suspend. Background polls and resumes them when needed.
    Added call to gomp_poll_threads in background loop.
2024-01-10 Optimize thread switching.
    Got the thread switching benchmark to work again.
2024-01-11 optimize thread polling
2024-03-20 Add KiCad files for the JLCPCB board.
    The JLCPCB board comes with the parts on the bottom size presoldered.
    All you have to do is solder the top side and connectors.
    Updated README.
    Comments and minor firmware fine-tuning.
    [H503-0.2-BOM.csv, H503-0.2-BOM.xlsx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]
2024-05-15 Add a top-level makefile to create the missing .cyclo files
    This is to get rid of the warning about a pattern rule not making all
    its targets. This occurs because I use a custom GCC that does not
    support the -fcyclomatic-complexity option. You can turn the option off
    in the STM32 IDE's compiler settings, but the autogenerated Makefiles
    still contain .cyclo targets.
    Reorganize the directories under Core/Src.
2024-12-14 Copy updates from later work on the MSCP project, such as the temperature monitor.
    Update autogenerated libraries.
2024-12-19 Enable SPI2 for NOR flash
    This necessitated updating to the latest version of STM32CubeMX
    and its libraries.
    Reorganize stacks a bit, reduced sise of background and temperature
    monitor stacks, to gain space for FATFS later.
2024-12-20 Snapshot of more WIP; first compile without error, but not tested at all.
    [H503.ioc, SSPI.cpp, SSPI.h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]
2024-12-21 Correct the sector and block sizes.
    This snapshot has a semi-working FATFS. A FATFS image can be downloaded
    to the NOR flash via Xmodem.
    Add "disk activity LED".
    Erase chip does NOT work.
    [GpioCommand.cpp, H503.ioc, SSPI.cpp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]
2024-12-27 add code to invers dsata read/written to SPI NOR
    Not fully tested yet.
2025-01-25 snapshot: added code for SD card support for FATFS
    not working yet
    [H503.ioc, interp.cpp, main.c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]

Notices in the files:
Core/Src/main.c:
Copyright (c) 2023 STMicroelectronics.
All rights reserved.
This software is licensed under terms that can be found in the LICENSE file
